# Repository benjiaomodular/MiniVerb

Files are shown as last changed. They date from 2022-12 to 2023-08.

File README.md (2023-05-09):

# MiniVerb
A reverb module based around the Daisy Seed platform.

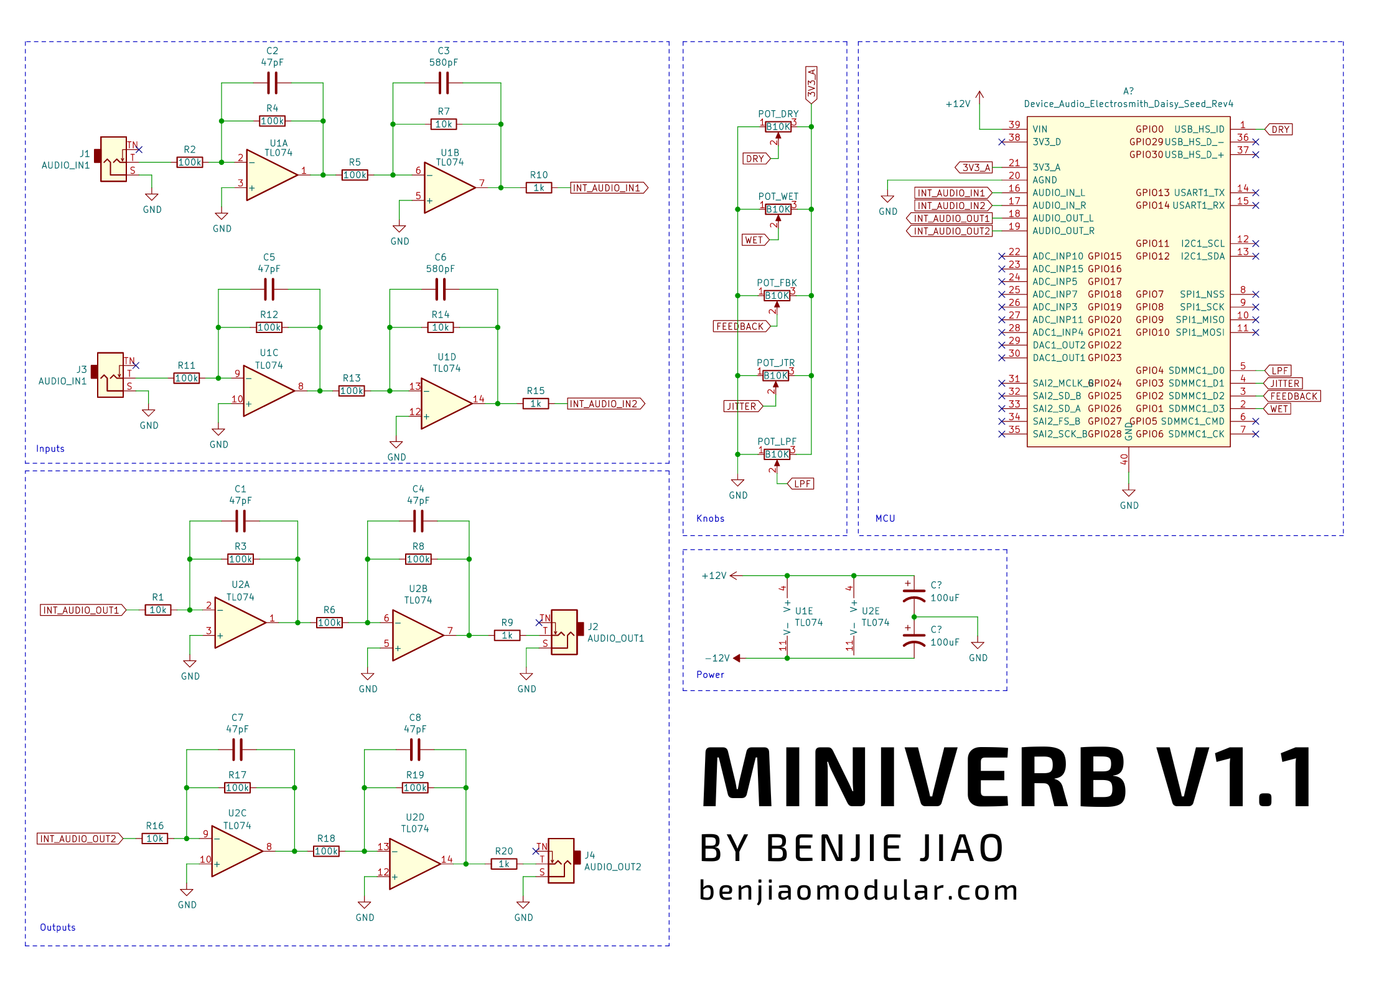
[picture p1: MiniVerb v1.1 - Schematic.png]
MiniVerb v1.1

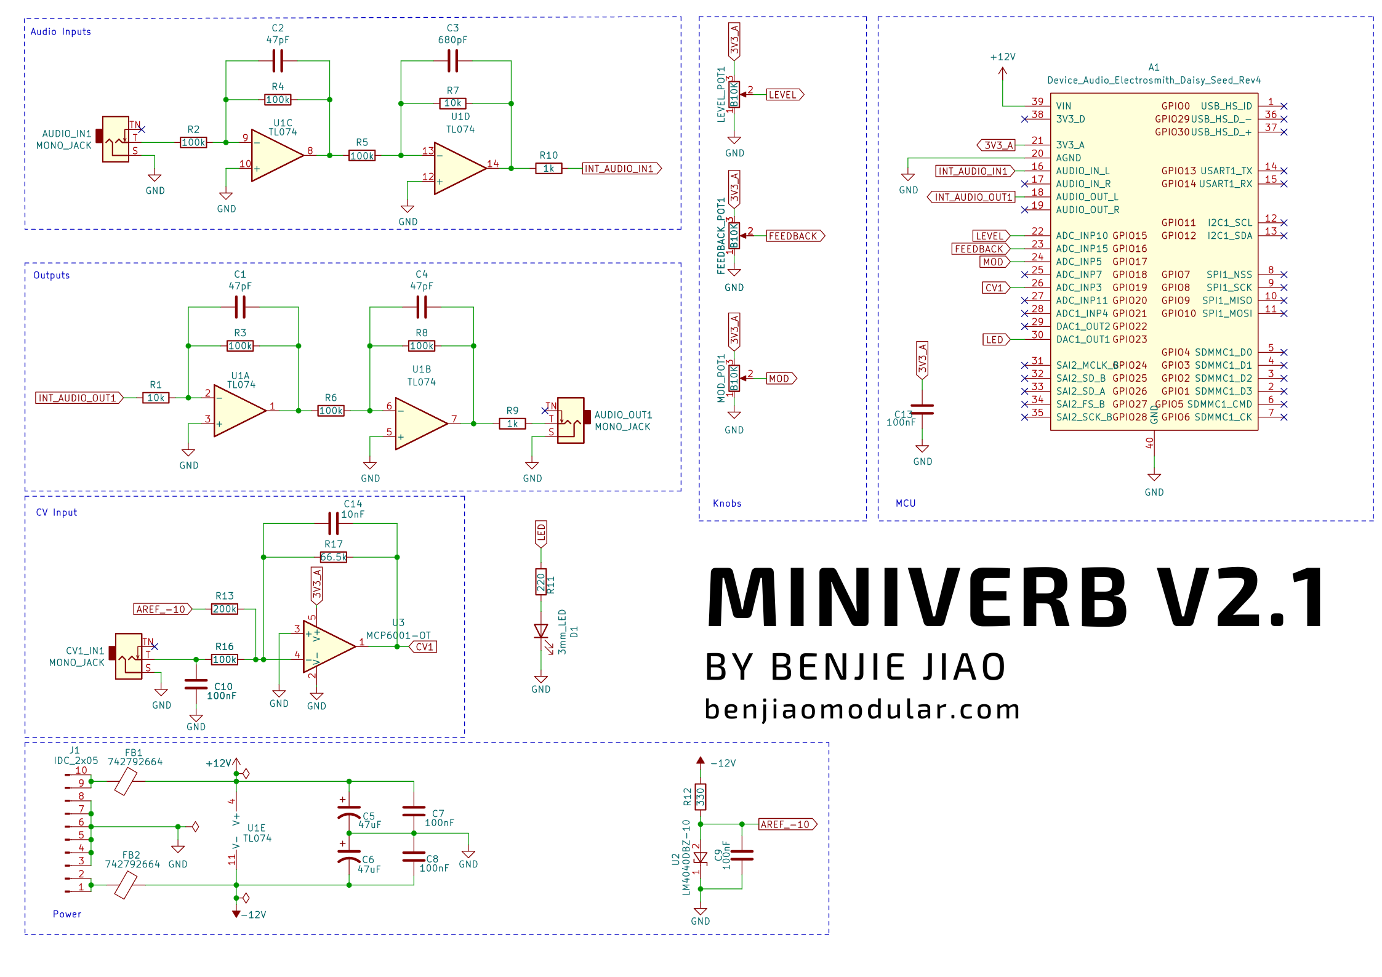
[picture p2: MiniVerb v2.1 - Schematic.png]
MiniVerb v2.1


## PCB Versions
### 2.1
Finally, a working SMT version

Download zip files from: [Hardware/MiniVerb v2.1/Fabrication](Hardware/MiniVerb%20v2.1/Fabrication)

### 2.0 (not working)
First SMT Release. This version was unusable.
- Added a single CV input

### 1.1
First batch of corrections
- Fixed pot connections
- Make IN(R) use IN(L) when no jack is inserted.

Download zip files from: [Hardware/MiniVerb v1.1/Fabrication](Hardware/MiniVerb%20v1.1/Fabrication)

### 1.0 (not working)
Initial release (does not work out of the box)
- Pots connected to the wrong pins on the Daisy

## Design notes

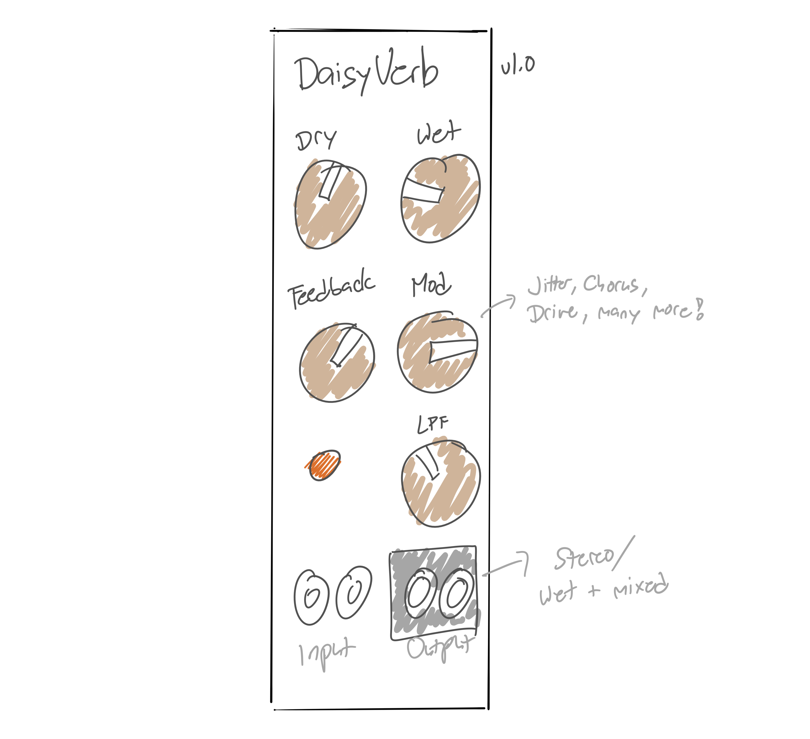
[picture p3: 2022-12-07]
DaisyVerb.png

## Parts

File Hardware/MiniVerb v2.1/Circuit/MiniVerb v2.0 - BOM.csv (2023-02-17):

Item | Qty | Reference(s) | Value | Footprint | Manufacturers Name | Manufacturers Part Number
1 | 1 | A1 | Device_Audio_Electrosmith_Daisy_Seed_Rev4 | daisy-seed:Device_Audio_Electrosmith_Daisy_Seed | Electro-Smith | Daisy_Seed_Rev4
2 | 3 | AUDIO_IN1, AUDIO_OUT1, CV1_IN1 | MONO_JACK | benjiaomodular:AudioJack_3.5mm | Tayda Electronics | PJ-3001F
3 | 3 | C1, C2, C4 | 47pF | Capacitor_SMD:C_0603_1608Metric_Pad1.08x0.95mm_HandSolder | YAGEO | CC0603JRNPO9BN470
4 | 1 | C3 | 680pF | Capacitor_SMD:C_0603_1608Metric_Pad1.08x0.95mm_HandSolder | Vishay / Vitramon | VJ0603Y681KXAAC
5 | 2 | C5, C6 | 47uF | Capacitor_SMD:C_0805_2012Metric_Pad1.18x1.45mm_HandSolder | Murata Electronics | GRM219R60J476ME44D
6 | 4 | C7, C8, C9, C13 | 100nF | Capacitor_SMD:C_0603_1608Metric_Pad1.08x0.95mm_HandSolder | YAGEO | CC0805KRX7R9BB104
7 | 1 | C14 | 10nF | Capacitor_SMD:C_0603_1608Metric_Pad1.08x0.95mm_HandSolder | YAGEO | CC0603JRX7R9BB103
8 | 1 | D1 | 3mm_LED | LED_THT:LED_D3.0mm | EKINGLUX | EL304RD
9 | 3 | FEEDBACK_POT1, LEVEL_POT1, MOD_POT1 | B10K | benjiaomodular:Potentiometer_RV09 | Alpha (Taiwan) | RD901F-40-15R1-B10K
10 | 1 | J1 | IDC_2x05 | Connector_IDC:IDC-Header_2x05_P2.54mm_Vertical | XKB Connectivity | X9555WV-2X05-6TV01
11 | 3 | R1, R7, R11 | 10k | Resistor_SMD:R_0603_1608Metric_Pad0.98x0.95mm_HandSolder | YAGEO | AC0603FR-0710KL
12 | 7 | R2, R3, R4, R5, R6, R8, R16 | 100k | Resistor_SMD:R_0603_1608Metric_Pad0.98x0.95mm_HandSolder | YAGEO | RC0603FR-07100KL
13 | 2 | R9, R10 | 1k | Resistor_SMD:R_0603_1608Metric_Pad0.98x0.95mm_HandSolder | YAGEO | RC0603FR-071KL
14 | 1 | R12 | 330 | Resistor_SMD:R_0603_1608Metric_Pad0.98x0.95mm_HandSolder | TE Connectivity / Holsworthy | CRG0603F330R
15 | 1 | R14 | 200k | Resistor_SMD:R_0603_1608Metric_Pad0.98x0.95mm_HandSolder | Bourns | CR0603-FX-2003ELF
16 | 1 | R17 | 66.5k | Resistor_SMD:R_0603_1608Metric_Pad0.98x0.95mm_HandSolder | YAGEO | RC0603FR-0766K5L
17 | 1 | TP1 | TP_12V | TestPoint:TestPoint_THTPad_1.0x1.0mm_Drill0.5mm | - | -
18 | 1 | TP2 | TP_-12V | TestPoint:TestPoint_THTPad_1.0x1.0mm_Drill0.5mm | - | -
19 | 1 | TP3 | TP_GND | TestPoint:TestPoint_Loop_D1.80mm_Drill1.0mm_Beaded | - | -
20 | 1 | TP4 | TP_-10V | TestPoint:TestPoint_THTPad_1.0x1.0mm_Drill0.5mm | - | -
21 | 1 | TP5 | TP_3.3V | TestPoint:TestPoint_THTPad_1.0x1.0mm_Drill0.5mm | - | -
22 | 1 | TP7 | TP_INPUT_BUFFER | TestPoint:TestPoint_THTPad_1.0x1.0mm_Drill0.5mm | - | -
23 | 1 | U1 | TL074 | Package_SO:SOIC-14_3.9x8.7mm_P1.27mm | Texas Instruments | TL074HIDYYR
24 | 1 | U2 | LM4040LP-10 | Package_TO_SOT_SMD:SOT-23_Handsoldering | Texas Instruments | LM4040CIM3-10.0/NOPB
25 | 1 | U3 | MCP6001-OT | Package_TO_SOT_SMD:SOT-23-5 | Microchip Technology / Atmel | MCP6001UT-I/OT

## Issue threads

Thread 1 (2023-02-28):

CV not working for v2

benjiao, 2023-02-28:

benjiao, 2023-02-28:
-10vref was reading- 6.7V. LM4040 footprint is inverted. Fixing this did not fix the CV issue yet

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

benjiao, 2023-02-28:
I think I found it. I was using the MCP6001U instead of MCP6001. Will close this once confirmed

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

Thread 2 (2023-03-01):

Footprint is a bit too wide for turned-pin low-profile sockets

benjiao, 2023-03-01:
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

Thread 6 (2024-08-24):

Delay.ino in v2 software is an empty file

codeophile, 2024-08-24:
Before I get started building this, I'd like to know if the software for it is complete. Can anyone tell me?

benjiao, 2024-12-01:
Hi! Sorry I didn't notice this right away. Yes, I've been using the Jitter and Octave software for a while now. I haven't had the time to finish the Delay firmware just yet, unfortunately.

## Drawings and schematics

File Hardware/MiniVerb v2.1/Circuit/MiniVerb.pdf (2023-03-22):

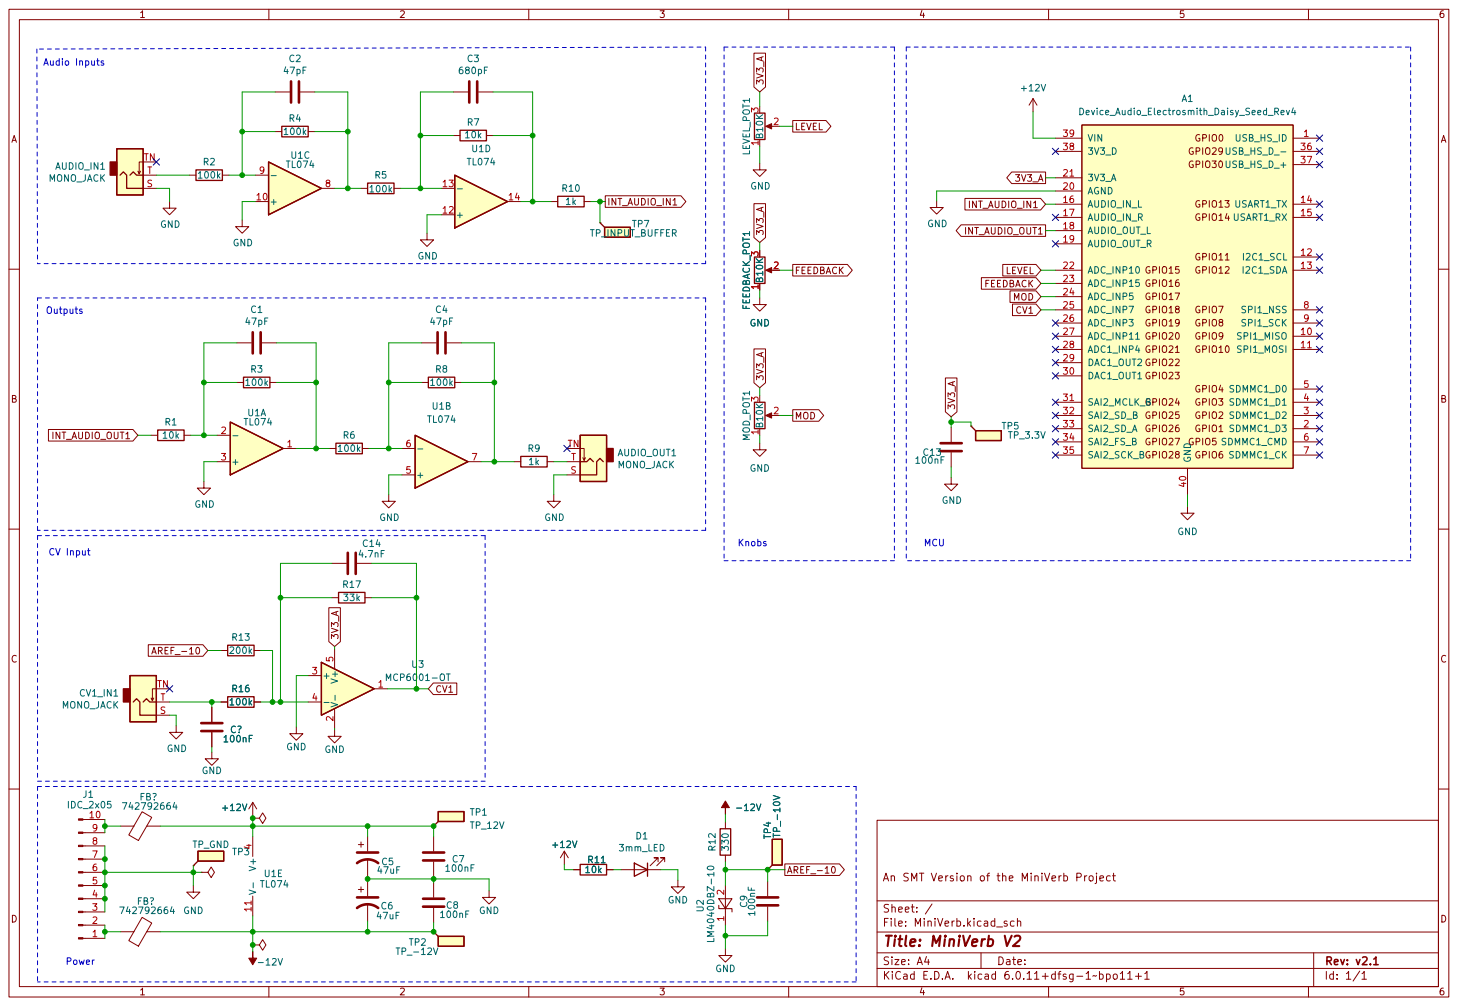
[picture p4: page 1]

Audio Inputs CV Input

File: MiniVerb.kicad_sch Sheet: / An SMT Version of the MiniVerb Project GND

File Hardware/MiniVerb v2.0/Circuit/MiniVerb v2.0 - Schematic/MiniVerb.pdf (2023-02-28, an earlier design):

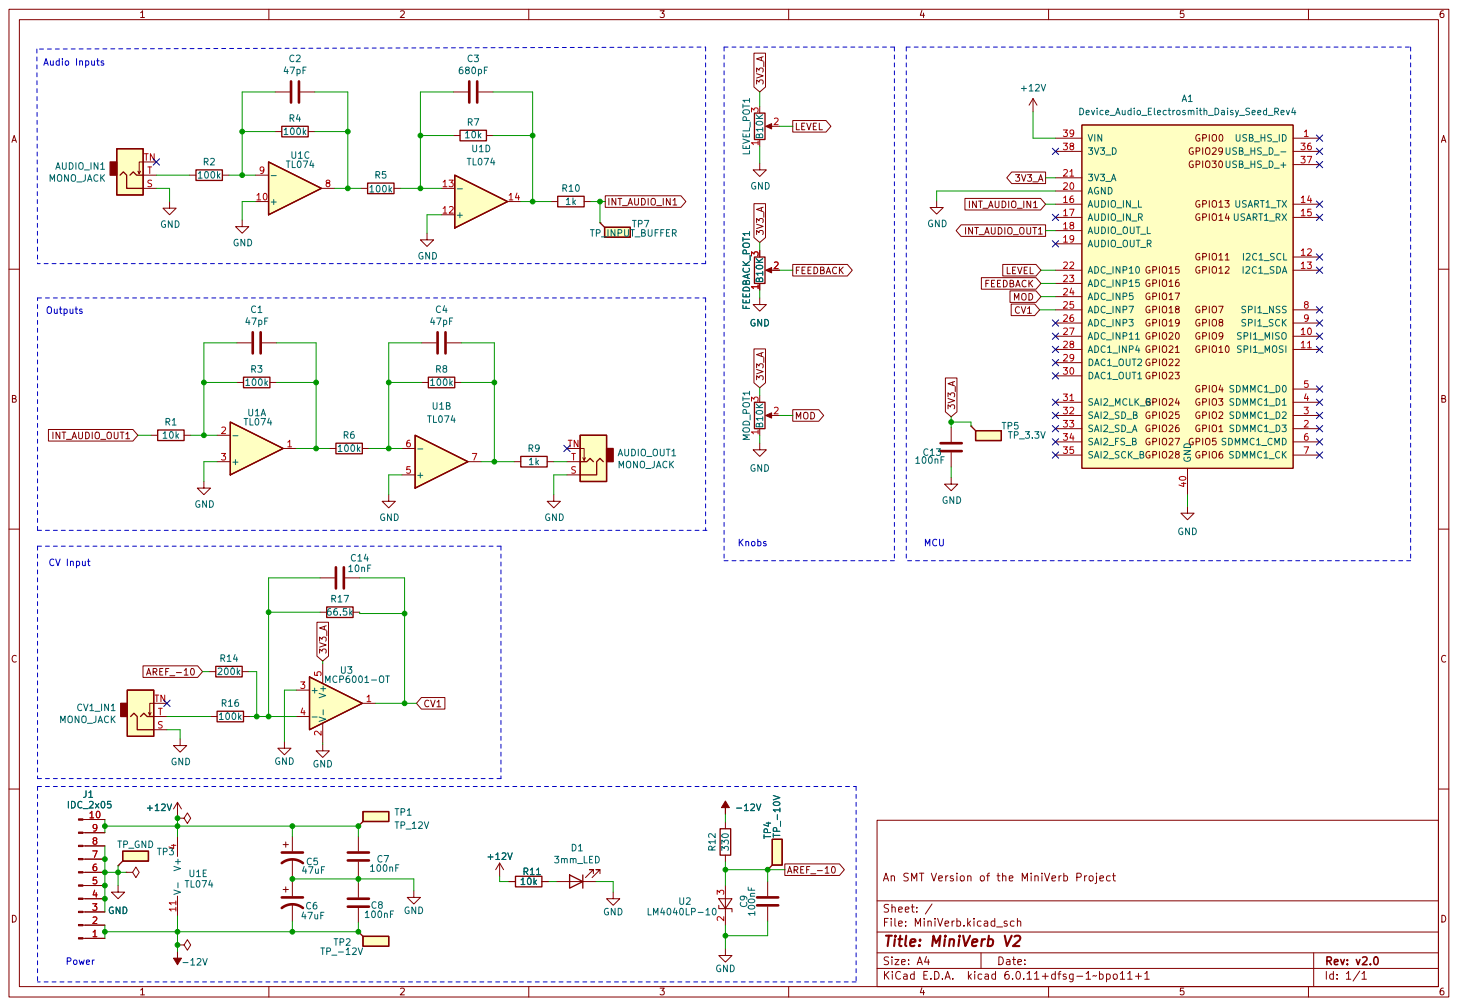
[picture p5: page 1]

File: MiniVerb.kicad_sch Sheet: / An SMT Version of the MiniVerb Project

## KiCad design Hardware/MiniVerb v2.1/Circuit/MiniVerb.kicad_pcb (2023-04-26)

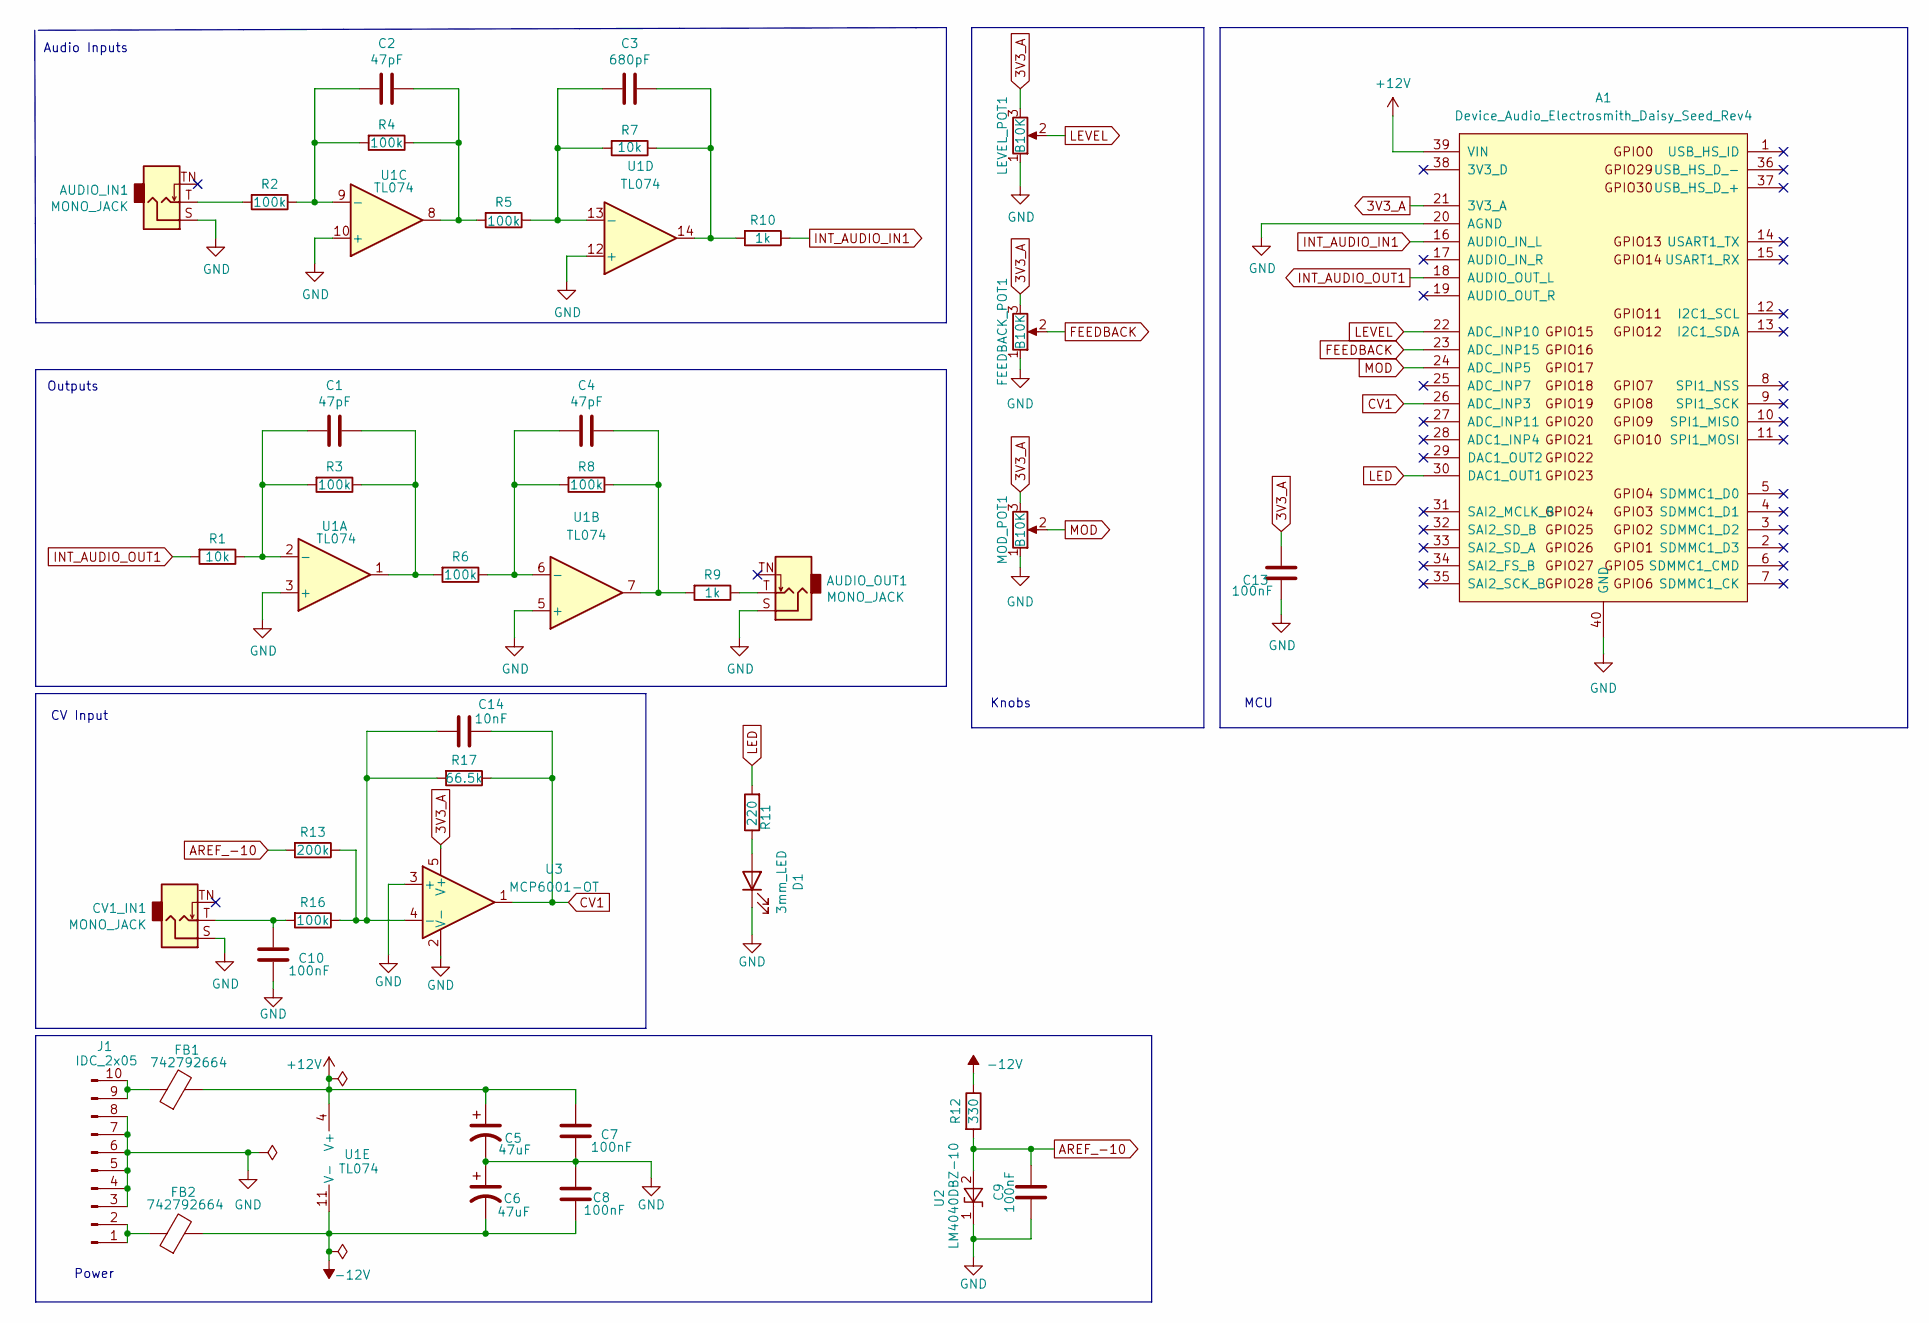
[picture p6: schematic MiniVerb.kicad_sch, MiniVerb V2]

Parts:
A1: Device_Audio_Electrosmith_Daisy_Seed_Rev4; Device_Audio_Electrosmith_Daisy_Seed
AUDIO_IN1: MONO_JACK; AudioJack_3.5mm; Manufacturers Part Numb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 PJ-3001F
AUDIO_OUT1: MONO_JACK; AudioJack_3.5mm; Manufacturers Part Numb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 PJ-3001F
C1, C2, C4: 47pF; C_0603_1608Metric_Pad1.08x0.95mm_HandSolder; Manufacturers Part Numb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 CC0603JRNPO9BN470
C3: 680pF; C_0603_1608Metric_Pad1.08x0.95mm_HandSolder; Manufacturers Part Numb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 VJ0603Y681KXAAC
C5, C6: 47uF; C_0805_2012Metric_Pad1.18x1.45mm_HandSolder; Manufacturers Part Numb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 GRM219R60J476ME44D
C7, C8, C9, C10, C13: 100nF; C_0603_1608Metric_Pad1.08x0.95mm_HandSolder; Manufacturers Part Numb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 CC0805KRX7R9BB104
C14: 10nF; C_0603_1608Metric_Pad1.08x0.95mm_HandSolder; Manufacturers Part Numb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 CC0603JRX7R9BB103
CV1_IN1: MONO_JACK; AudioJack_3.5mm; Manufacturers Part Numb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 PJ-3001F
D1: 3mm_LED; LED_D3.0mm; Manufacturers Part Numb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 EL304RD; LCSC Part # C2856645
FB1, FB2: 742792664; C_0603_1608Metric_Pad1.08x0.95mm_HandSolder; Manufacturers Part Numb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 742792664
FEEDBACK_POT1: B10K; Potentiometer_RV09_NoBracket; Manufacturers Part Numb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 RD901F-40-15R1-B10K
J1: IDC_2x05; IDC-Header_2x05_P2.54mm_Vertical; Manufacturers Part Numb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 X9555WV-2X05-6TV01; LCSC Part # C706914
LEVEL_POT1: B10K; Potentiometer_RV09_NoBracket; Manufacturers Part Numb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 RD901F-40-15R1-B10K
MOD_POT1: B10K; Potentiometer_RV09_NoBracket; Manufacturers Part Numb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 RD901F-40-15R1-B10K
R1, R7: 10k; R_0603_1608Metric_Pad0.98x0.95mm_HandSolder; Manufacturers Part Numb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 AC0603FR-0710KL
R2, R3, R4, R5, R6, R8, R16: 100k; R_0603_1608Metric_Pad0.98x0.95mm_HandSolder; Manufacturers Part Numb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 RC0603FR-07100KL
R9, R10: 1k; R_0603_1608Metric_Pad0.98x0.95mm_HandSolder; Manufacturers Part Numb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 RC0603FR-071KL
R11: 220; R_0603_1608Metric_Pad0.98x0.95mm_HandSolder; Mfg # AC0603FR-0710KL; LCSC Part # C116677
R12: 330; R_0603_1608Metric_Pad0.98x0.95mm_HandSolder; Manufacturers Part Numb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 CRG0603F330R
R13: 200k; R_0603_1608Metric_Pad0.98x0.95mm_HandSolder; Manufacturers Part Numb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 RC0603FR-07100KL
R17: 66.5k; R_0603_1608Metric_Pad0.98x0.95mm_HandSolder; Manufacturers Part Numb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 RC0603FR-0766K5L
U1: TL074; SOIC-14_3.9x8.7mm_P1.27mm; Manufacturers Part Numb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 TL074HIDYYR
U2: LM4040DBZ-10; SOT-23; Manufacturers Part Numb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 LM4040CIM3-10.0/NOPB
U3: MCP6001-OT; SOT-23-5; Manufacturers Part Numb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 MCP6001T-E/OT

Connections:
3V3_A: A1.21 (3V3_A), C13.1, FEEDBACK_POT1.3, LEVEL_POT1.3, MOD_POT1.3, U3.5 (V+)
+12V: A1.39 (VIN), C5.1, C7.1, FB1.2, U1.4 (V+)
-12V: C6.2, C8.2, FB2.2, R12.1, U1.11 (V-)
AREF_-10: C9.1, R12.2, R13.2, U2.2 (A)
CV1: A1.26 (ADC_INP3), C14.1, R17.1, U3.1
FEEDBACK: A1.23 (ADC_INP15), FEEDBACK_POT1.2
GND: A1.20 (AGND), A1.40 (GND), AUDIO_IN1.S, AUDIO_OUT1.S, C5.2, C6.1, C7.2, C8.1, C9.2, C10.2, C13.2, CV1_IN1.S, D1.1 (K), FEEDBACK_POT1.1, J1.3, J1.4, J1.5, J1.6, J1.7, J1.8, LEVEL_POT1.1, MOD_POT1.1, U1.3 (+), U1.5 (+), U1.10 (+), U1.12 (+), U2.1 (K), U3.2 (V-), U3.3 (+)
INT_AUDIO_IN1: A1.16 (AUDIO_IN_L), R10.1
INT_AUDIO_OUT1: A1.18 (AUDIO_OUT_L), R1.2
LED: A1.30 (DAC1_OUT1), R11.2
LEVEL: A1.22 (ADC_INP10), LEVEL_POT1.2
MOD: A1.24 (ADC_INP5), MOD_POT1.2
unnamed: AUDIO_IN1.T, R2.2
unnamed: AUDIO_OUT1.T, R9.1
unnamed: C1.1, R3.1, R6.2, U1.1
unnamed: C1.2, R1.1, R3.2, U1.2 (-)
unnamed: C2.1, R4.1, R5.2, U1.8
unnamed: C2.2, R2.1, R4.2, U1.9 (-)
unnamed: C3.1, R7.1, R10.2, U1.14
unnamed: C3.2, R5.1, R7.2, U1.13 (-)
unnamed: C4.1, R8.1, R9.2, U1.7
unnamed: C4.2, R6.1, R8.2, U1.6 (-)
unnamed: C10.1, CV1_IN1.T, R16.2
unnamed: C14.2, R13.1, R16.1, R17.2, U3.4 (-)
unnamed: D1.2 (A), R11.1
unnamed: FB1.1, J1.9, J1.10
unnamed: FB2.1, J1.1, J1.2

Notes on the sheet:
CV Input
Power
Outputs
Knobs
MCU
Audio Inputs

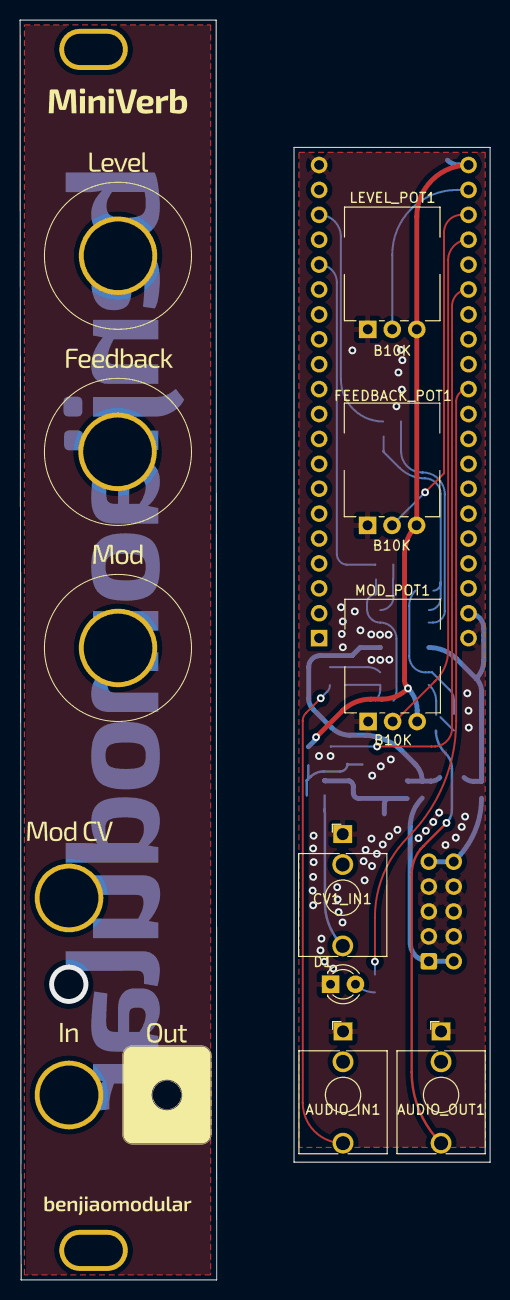
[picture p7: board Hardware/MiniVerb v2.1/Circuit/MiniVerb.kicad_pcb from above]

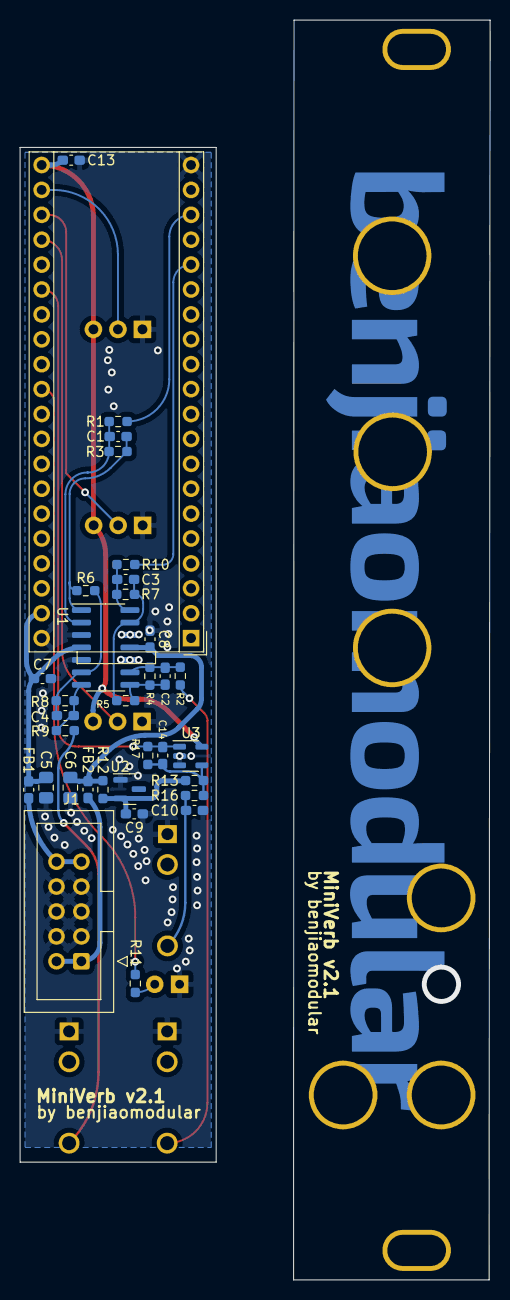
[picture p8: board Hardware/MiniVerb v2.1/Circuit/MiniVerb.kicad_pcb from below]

Board: 2 copper layers, 20.0 x 103.5 mm, 41 parts (34 on the bottom side), 27 nets.

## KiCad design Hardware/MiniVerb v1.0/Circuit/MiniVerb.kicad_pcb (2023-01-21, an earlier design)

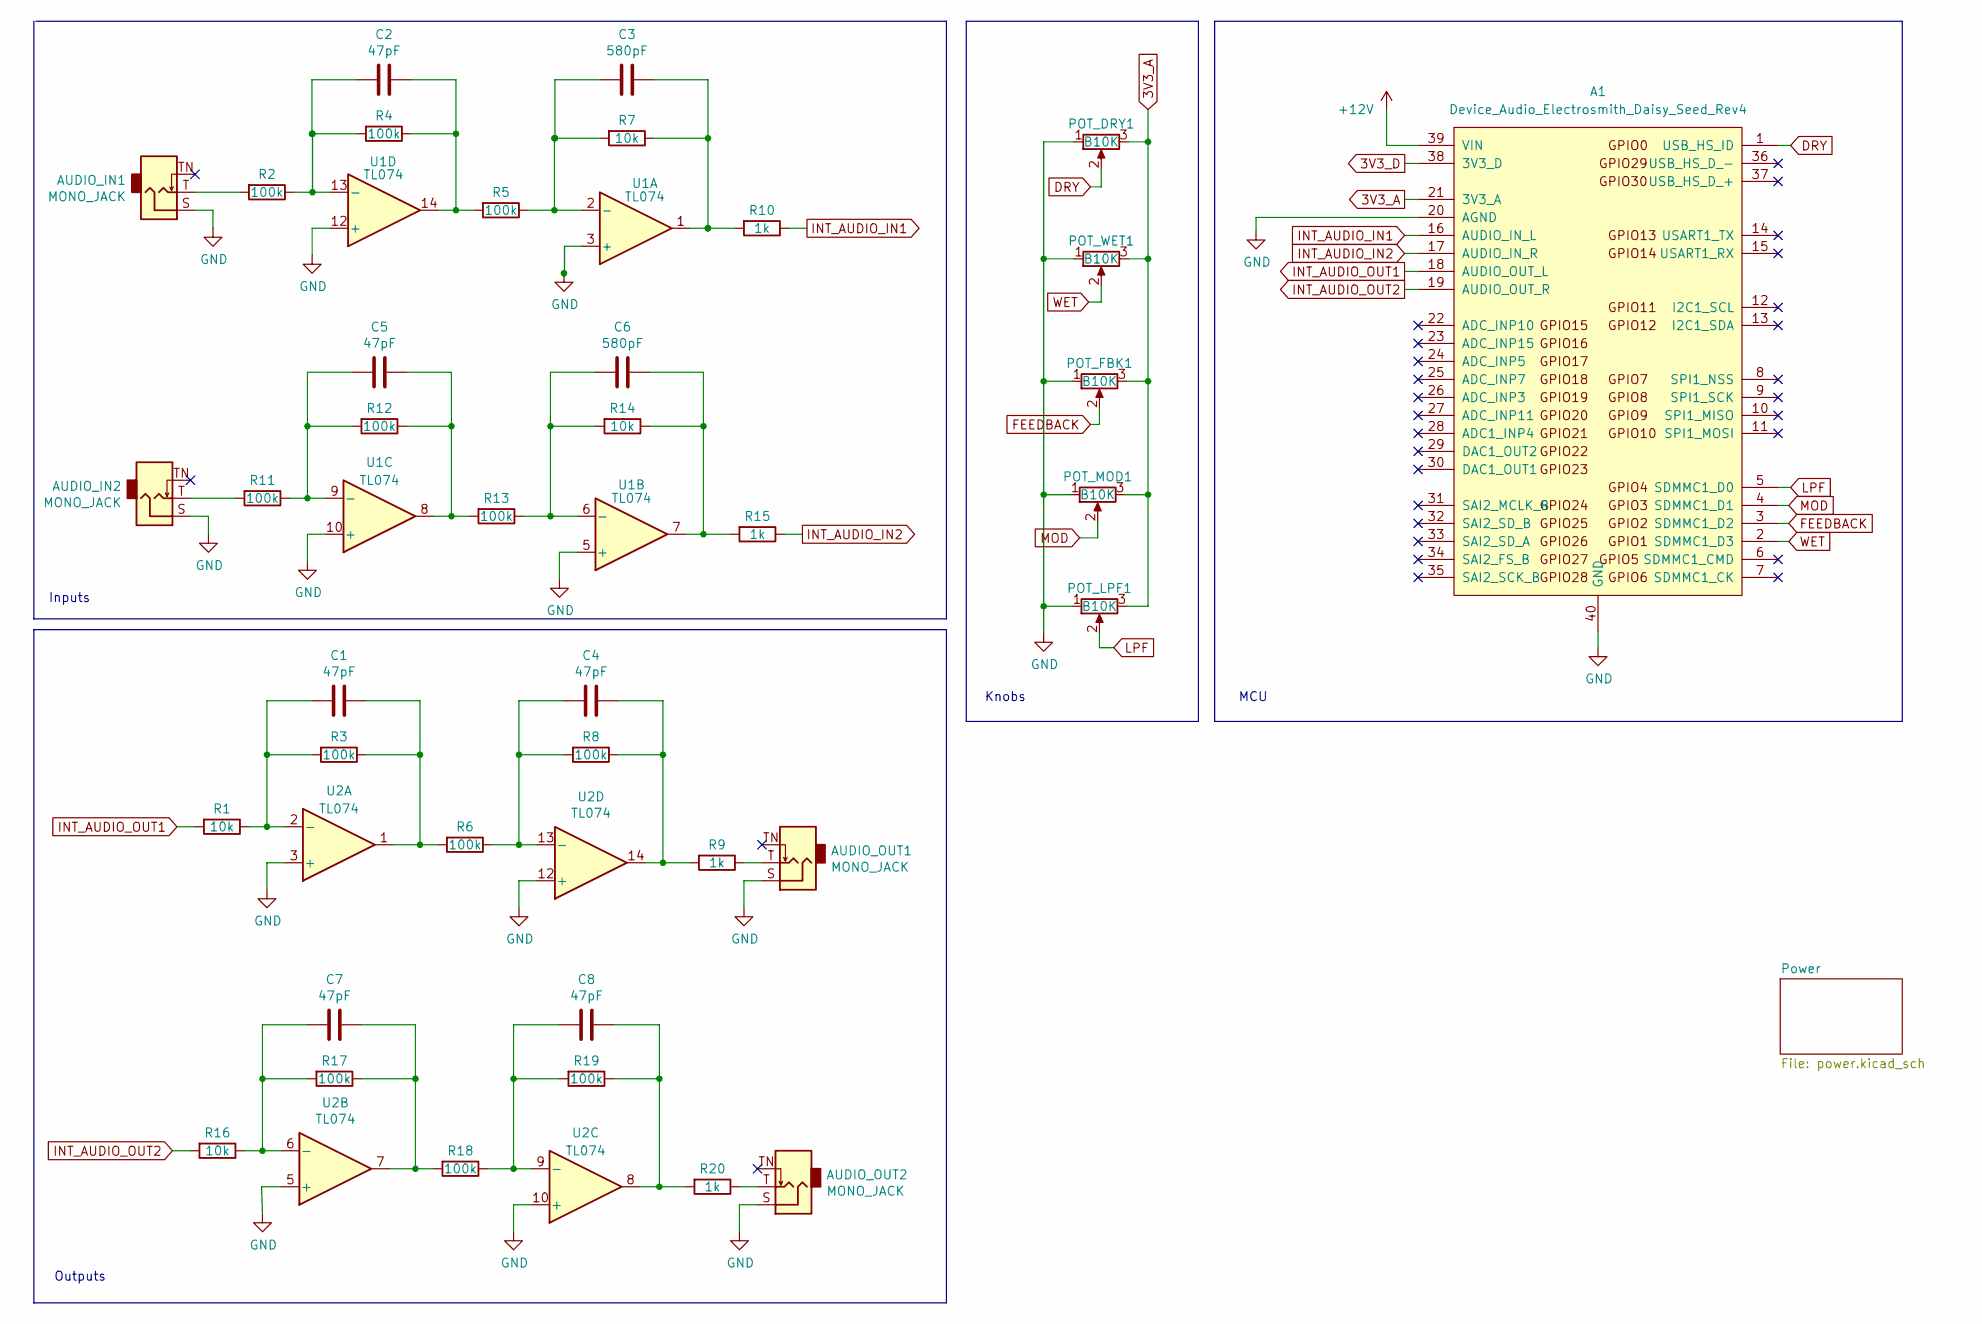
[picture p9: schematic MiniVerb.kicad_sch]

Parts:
A1: Device_Audio_Electrosmith_Daisy_Seed_Rev4; Device_Audio_Electrosmith_Daisy_Seed
AUDIO_IN1, AUDIO_IN2: MONO_JACK; AudioJack_3.5mm
AUDIO_OUT1, AUDIO_OUT2: MONO_JACK; AudioJack_3.5mm
C1, C2, C4, C5, C7, C8: 47pF; Capacitor_Disc_D3.8mm_W2.6mm_P2.50mm
C3, C6: 580pF; Capacitor_Rect_L7.2mm_W2.5mm_P5.00mm
POT_DRY1: B10K; Potentiometer_RV09
POT_FBK1: B10K; Potentiometer_RV09
POT_LPF1: B10K; Potentiometer_RV09
POT_MOD1: B10K; Potentiometer_RV09
POT_WET1: B10K; Potentiometer_RV09
R1, R7, R14, R16: 10k; Resistor_L6.3mm_D2.5mm_P7.62mm_Horizontal
R2, R3, R4, R5, R6, R8, R11, R12, R13, R17, R18, R19: 100k; Resistor_L6.3mm_D2.5mm_P7.62mm_Horizontal
R9, R10, R15, R20: 1k; Resistor_L6.3mm_D2.5mm_P7.62mm_Horizontal
U1, U2: TL074; DIP-14_W7.62mm

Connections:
3V3_A: A1.21 (3V3_A), POT_DRY1.3, POT_FBK1.3, POT_LPF1.3, POT_MOD1.3, POT_WET1.3
3V3_D: A1.38 (3V3_D)
+12V: A1.39 (VIN); also elsewhere on the board
DRY: A1.1 (USB_HS_ID), POT_DRY1.2
FEEDBACK: A1.3 (SDMMC1_D2), POT_FBK1.2
GND: A1.20 (AGND), A1.40 (GND), AUDIO_IN1.S, AUDIO_IN2.S, AUDIO_OUT1.S, AUDIO_OUT2.S, POT_DRY1.1, POT_FBK1.1, POT_LPF1.1, POT_MOD1.1, POT_WET1.1, U1.3 (+), U1.5 (+), U1.10 (+), U1.12 (+), U2.3 (+), U2.5 (+), U2.10 (+), U2.12 (+); also elsewhere on the board
INT_AUDIO_IN1: A1.16 (AUDIO_IN_L), R10.1
INT_AUDIO_IN2: A1.17 (AUDIO_IN_R), R15.1
INT_AUDIO_OUT1: A1.18 (AUDIO_OUT_L), R1.2
INT_AUDIO_OUT2: A1.19 (AUDIO_OUT_R), R16.2
LPF: A1.5 (SDMMC1_D0), POT_LPF1.2
MOD: A1.4 (SDMMC1_D1), POT_MOD1.2
unnamed: AUDIO_IN1.T, R2.2
unnamed: AUDIO_IN2.T, R11.2
unnamed: AUDIO_OUT1.T, R9.1
unnamed: AUDIO_OUT2.T, R20.1
unnamed: C1.1, R3.1, R6.2, U2.1
unnamed: C1.2, R1.1, R3.2, U2.2 (-)
unnamed: C2.1, R4.1, R5.2, U1.14
unnamed: C2.2, R2.1, R4.2, U1.13 (-)
unnamed: C3.1, R7.1, R10.2, U1.1
unnamed: C3.2, R5.1, R7.2, U1.2 (-)
unnamed: C4.1, R8.1, R9.2, U2.14
unnamed: C4.2, R6.1, R8.2, U2.13 (-)
unnamed: C5.1, R12.1, R13.2, U1.8
unnamed: C5.2, R11.1, R12.2, U1.9 (-)
unnamed: C6.1, R14.1, R15.2, U1.7
unnamed: C6.2, R13.1, R14.2, U1.6 (-)
unnamed: C7.1, R17.1, R18.2, U2.7
unnamed: C7.2, R16.1, R17.2, U2.6 (-)
unnamed: C8.1, R19.1, R20.2, U2.8
unnamed: C8.2, R18.1, R19.2, U2.9 (-)
WET: A1.2 (SDMMC1_D3), POT_WET1.2

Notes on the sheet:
Inputs
Outputs
Knobs
MCU

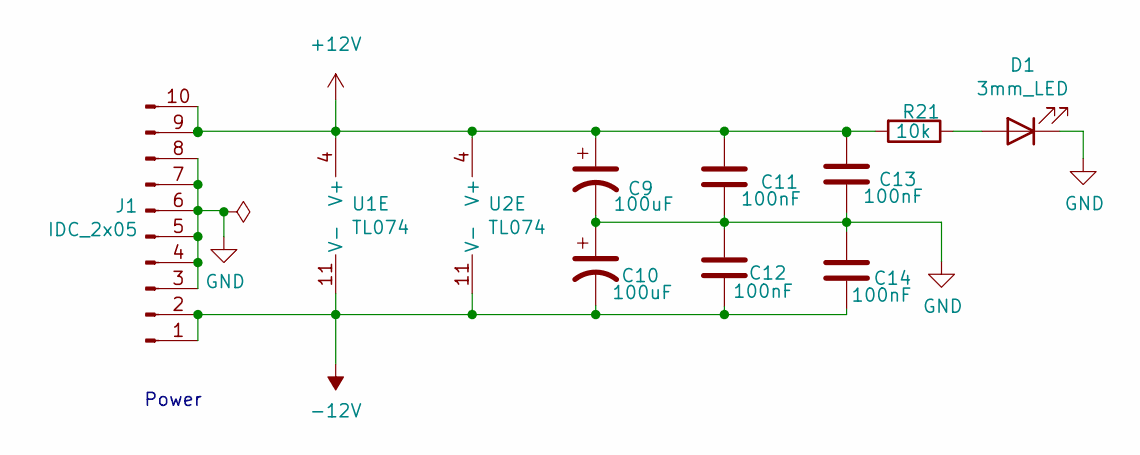
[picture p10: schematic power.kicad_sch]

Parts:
C9, C10: 100uF; Capacitor_Radial_D5.0mm_P2.5mm
C11, C12, C13, C14: 100nF; Capacitor_Rect_L7.2mm_W2.5mm_P5.00mm
D1: 3mm_LED; LED_D3.0mm; Manufacturers Part Numb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 EL304RD; LCSC Part # C2856645
J1: IDC_2x05; IDC-Header_2x05_P2.54mm_Vertical; Manufacturers Part Numb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 X9555WV-2X05-6TV01; LCSC Part # C706914
R21: 10k; Resistor_L6.3mm_D2.5mm_P7.62mm_Horizontal; Mfg # AC0603FR-0710KL; LCSC Part # C116677
U1, U2: TL074; DIP-14_W7.62mm

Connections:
+12V: C9.1, C11.1, C13.1, J1.9, J1.10, R21.2, U1.4 (V+), U2.4 (V+); also elsewhere on the board
-12V: C10.2, C12.2, C14.2, J1.1, J1.2, U1.11 (V-), U2.11 (V-)
GND: C9.2, C10.1, C11.2, C12.1, C13.2, C14.1, D1.1 (K), J1.3, J1.4, J1.5, J1.6, J1.7, J1.8; also elsewhere on the board
unnamed: D1.2 (A), R21.1

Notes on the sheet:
Power

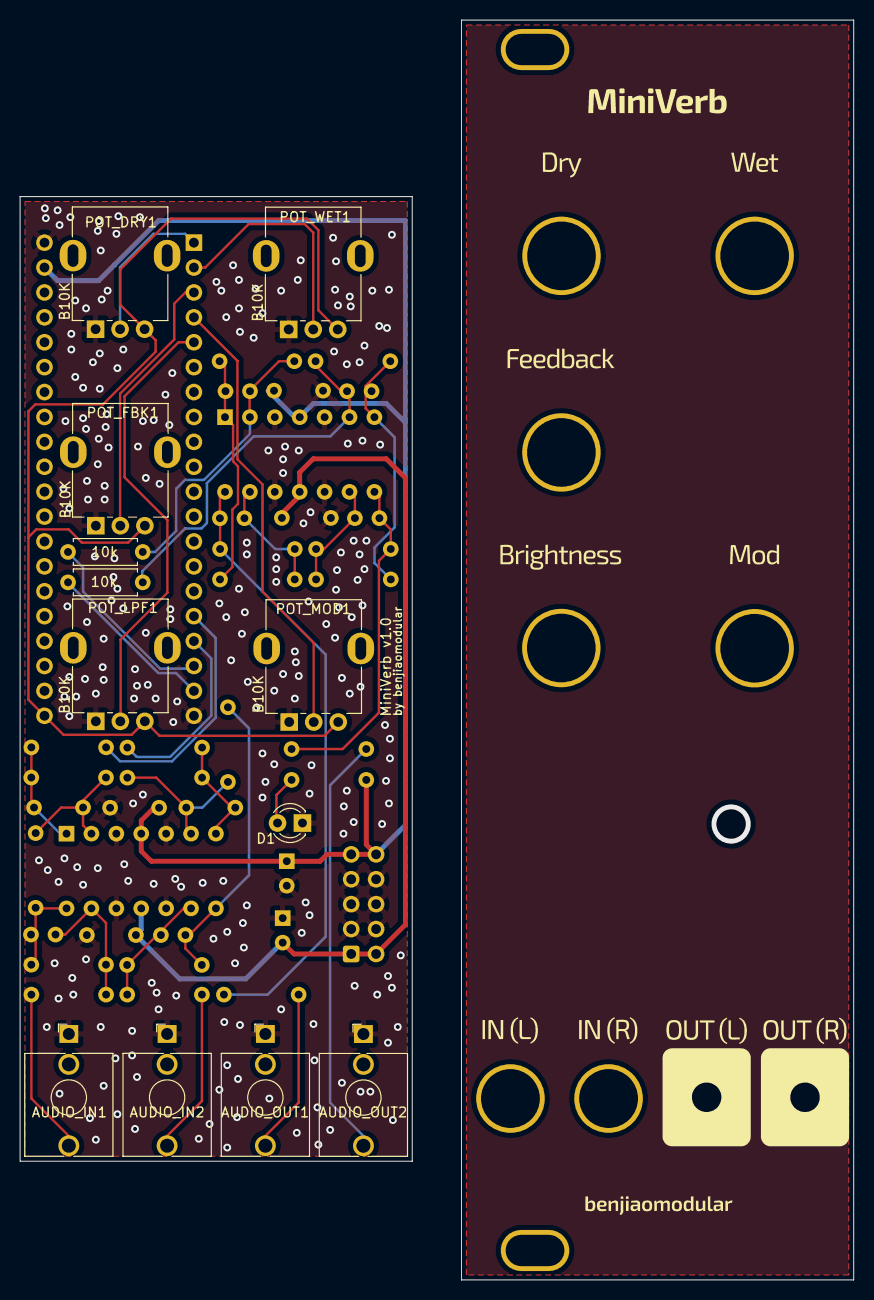
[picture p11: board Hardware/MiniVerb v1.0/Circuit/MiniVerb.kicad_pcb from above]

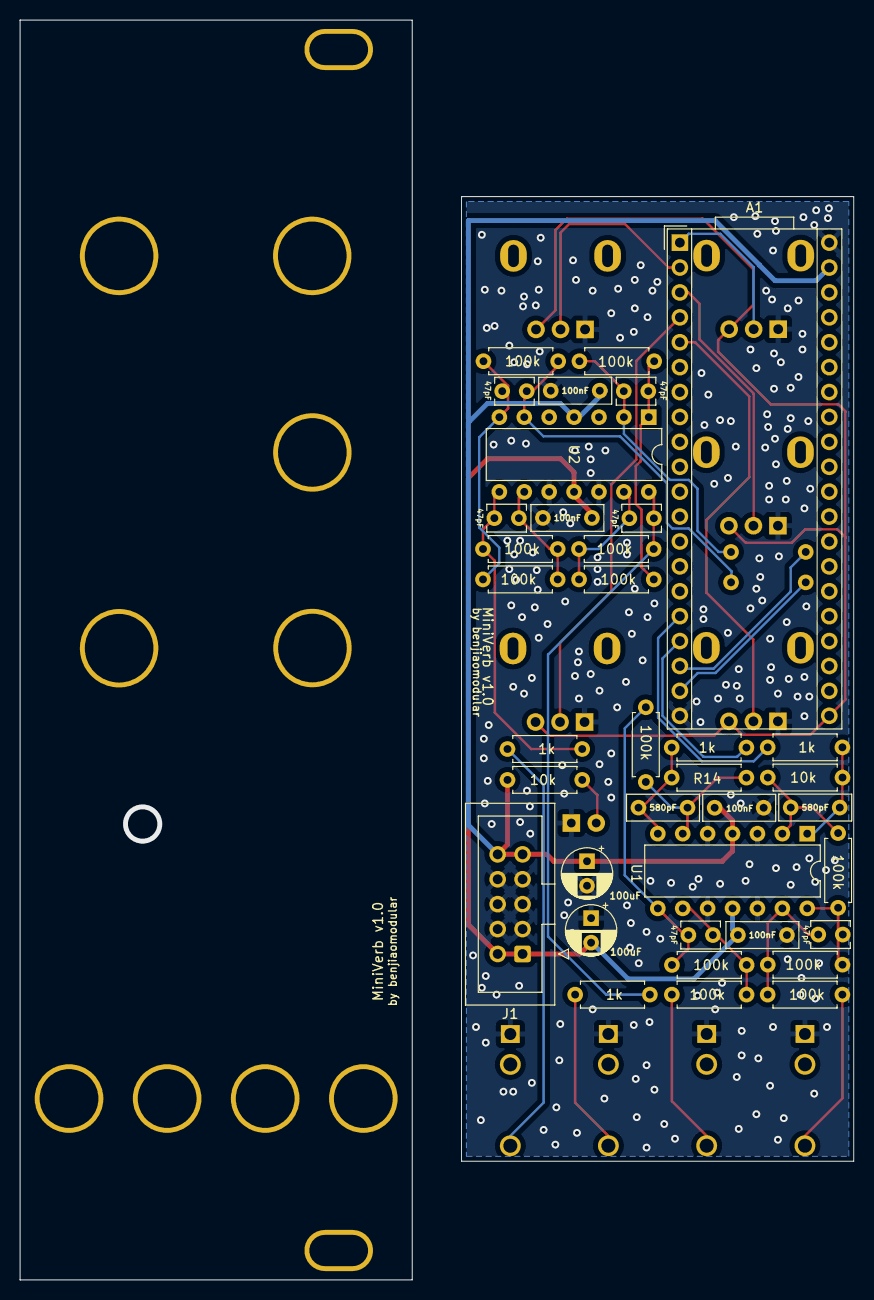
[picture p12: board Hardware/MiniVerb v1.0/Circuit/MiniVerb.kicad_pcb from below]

Board: 2 copper layers, 40.0 x 98.4 mm, 49 parts (37 on the bottom side), 34 nets.

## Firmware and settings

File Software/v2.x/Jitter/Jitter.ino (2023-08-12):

// For benjiaomodular MiniVerb v2.x
// Based on reverbsc by Stephen Hensley

#include "DaisyDuino.h"

DaisyHardware hw;

size_t num_channels;
float sample_rate;
static int LED_PIN = 23;
static int KNOB_1 = A0;
static int KNOB_2 = A1;
static int KNOB_3 = A2;
static int CV_1 = A4;

ReverbSc DSY_SDRAM_BSS verb;
static Jitter jitter;

float level, feedback, cv, cv_offset, mod;

float CtrlVal(uint8_t pin) {
  analogReadResolution(16);
  return (analogRead(pin)) / 65535.f;
}

void AudioCallback(float **in, float **out, size_t size) {
  float dryIn, verbOut;
  float jitter_out;

  level = CtrlVal(KNOB_1); // pin 22
  feedback = CtrlVal(KNOB_2); // pin 23

  cv = 1-CtrlVal(CV_1); // pin 26
  cv_offset = CtrlVal(KNOB_3) * 2.f - 1.f; // pin 24
  mod = constrain(cv + cv_offset, 0.f, 1.f);

  analogWrite(LED_PIN, constrain(mod * 255.f, 0, 255));

  verb.SetFeedback(0.8 + 0.2 * feedback);
  verb.SetLpFreq(15000.0f);

  for (size_t i = 0; i < size; i++) {
    dryIn = in[0][i];
    jitter_out = jitter.Process();
    
    verb.Process(dryIn, 0, &verbOut, 0);
    out[0][i] = dryIn + verbOut * ((1 - mod) + (jitter_out * mod)) * level;

  }
}

void setup() {
  // Initialize for Daisy pod at 48kHz
  hw = DAISY.init(DAISY_SEED, AUDIO_SR_48K);
  num_channels = hw.num_channels;
  sample_rate = DAISY.get_samplerate();
  
  pinMode(LED_PIN, OUTPUT);

  // Initialize reverb
  verb.Init(sample_rate);
  verb.SetFeedback(0.95f);
  verb.SetLpFreq(18000.0f);

  jitter.Init(sample_rate);
  jitter.SetAmp(1);
  jitter.SetCpsMin(1);
  jitter.SetCpsMax(25);

  level = 0.1f;
  DAISY.begin(AudioCallback);
}

void loop() {
}

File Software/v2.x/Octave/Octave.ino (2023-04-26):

// For benjiaomodular MiniVerb v2.x

// -- References --
// Based on reverbsc and pitchshifter by Stephen Hensley
// https://github.com/electro-smith/DaisyDuino/blob/master/examples/Seed/reverbsc/reverbsc.ino
// https://github.com/electro-smith/DaisyDuino/blob/master/examples/Seed/pitchshifter/pitchshifter.ino

#include "DaisyDuino.h"

DaisyHardware hw;

size_t num_channels;
float sample_rate;
static int LED_PIN = 23;

ReverbSc DSY_SDRAM_BSS verb;
PitchShifter ps;

float level, feedback, cv, cv_offset, mod;

float CtrlVal(uint8_t pin) {
  analogReadResolution(16);
  return (analogRead(pin)) / 65535.f;
}

void MyCallback(float **in, float **out, size_t size) {
  float dryIn, verbOut;
  float shifted;

  for (size_t i = 0; i < size; i++) {
    dryIn = in[0][i];
    shifted = ps.Process(dryIn);
    
    verb.Process(dryIn +  shifted * mod, 0, &verbOut, 0);
    out[0][i] = dryIn + verbOut * level;

  }
}

void setup() {

  // Initialize for Daisy pod at 48kHz
  hw = DAISY.init(DAISY_SEED, AUDIO_SR_48K);
  num_channels = hw.num_channels;
  sample_rate = DAISY.get_samplerate();
  
  pinMode(LED_PIN, OUTPUT);

  // Initialize reverb
  verb.Init(sample_rate);
  verb.SetFeedback(0.95f);
  verb.SetLpFreq(18000.0f);

  ps.Init(sample_rate);
  ps.SetTransposition(12.0f);

  level = 0.1f;
  DAISY.begin(MyCallback);
}

void loop() {
  level = CtrlVal(A0); // pin 22
  feedback = CtrlVal(A1); // pin 23

  cv = 1-CtrlVal(A4); // pin 26
  cv_offset = CtrlVal(A2) * 2.f - 1.f; // pin 24
  mod = constrain(cv + cv_offset, 0.f, 1.f);

  analogWrite(LED_PIN, constrain(mod * 255.f, 0, 255));

  verb.SetFeedback(0.8 + 0.2 * feedback);
  verb.SetLpFreq(15000.0f);
}

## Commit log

2022-12-14 initial panel
    [MiniVerb.kicad_pcb]
2023-01-21 Fixed mistakes from v1.0
    [CV Inputs.kicad_sch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]
2023-01-24 Use TN pin for IN (R)
    [MiniVerb.kicad_sch]
2023-02-02 Added SMT version
    [CV Inputs.kicad_sch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]
2023-02-02 Added gerber files for v1.1 front panel
    [MiniVerb - Main-B_Cu.gbr, MiniVerb - Main-B_Fab.gbr, MiniVerb - Main-B_Mask.gbr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]
2023-02-02 Fixed stereo reverb output
    [DaisyVerb.ino]
2023-02-10 Added BOM
    [MiniVerb v1.1 - BOM.csv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]
2023-02-10 Added schematics
2023-02-10 Added link to gerber files
2023-02-17 Updated BOM
    [CV Inputs.kicad_sch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]
2023-02-17 Updated bom zip
2023-02-17 Added pin headers
    [MiniVerb v1.1 - BOM.csv]
2023-03-01 Updated front panel :
    [MiniVerb - Front-B_Cu.gbr, MiniVerb - Front-B_Mask.gbr, MiniVerb - Front-B_Paste.gbr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]
2023-03-22 working software and hardware for v2.1
    [CV Inputs.kicad_sch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]
2023-04-26 cleanup and ibom
    [CV Inputs.kicad_sch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]
2023-05-09 Added v2.1 to docs
    [MiniVerb 2.1 - Front.kicad_pcb]
2023-08-12 Marked broken gerbers
    [MiniVerb - Front-B_Cu.gbr, MiniVerb - Front-B_Fab.gbr, MiniVerb - Front-B_Mask.gbr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]
2023-08-24 Update MiniVerb.ino
    Add missing slashes for comment
    [MiniVerb.ino]
